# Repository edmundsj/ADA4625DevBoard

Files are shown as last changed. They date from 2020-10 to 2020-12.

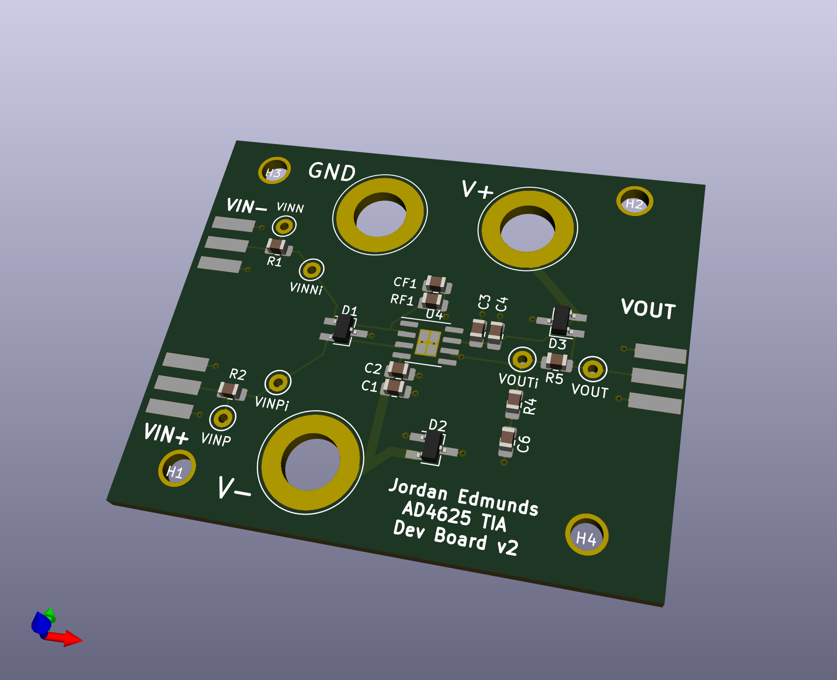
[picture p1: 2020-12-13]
tia_dev_board_image.png

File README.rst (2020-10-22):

ADA4625 TIA Development Board
===============================
This is a development board for the ADA4625 used as a low-noise a transimpedance amplifier.

Features
----------
- Low noise (140nV/rtHz measured at output with 1MOhm resistor, 140fA/rtHz input-referred)
- M3 standoffs
- Separate SMA inputs for + and -
- Power supplied by banana jacks (V+, V-, GND)
- Optional ESD protection diodes and output load filter
- Test points galore

Issues in Version 1
--------------------
- [FIXED v2.1] Gerbers not updated from v1
- [FIXED v2] No labeling of power, input/outputs
- [FIXED v2] board was unnecessarily large
- [FIXED v2]No name / version number on board

Bill of Materials
-------------------

.. csv-table::
    :header-rows: 1
    :file: bom.csv
    :widths: 25 25 25 25 25

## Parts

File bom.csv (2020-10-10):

Part Name | Quantity | Source | Catalog Number | Link
15V TVS Diode | 4 | Digikey | 1727-3813-1-ND | `1727-3813-1-ND <https://www.digikey.com/product-detail/en/nexperia-usa-inc/PESD15VL2BT-215/1727-3813-1-ND/1530818>`_
Banana Jack | 3 | Digikey | 36-575-4-ND | `36-575-4-ND <https://www.digikey.com/products/en?keywords=36-575-4-ND>`_
SMA 50Ohm Terminator | 1 | Digikey | ACX1251-ND | `ACX1251-ND <https://www.digikey.com/products/en?keywords=ACX1251-ND>`_
1MOhm Resistor | 1 | Digikey | 311-1.00MCRCT-ND | `311-1.00MCRCT-ND <https://www.digikey.com/products/en?keywords=311-1.00MCRCT-ND>`_
4.7MOhm Resistor | 1 | Digikey | RHM4.70MAHCT-ND | `RHM4.70MAHCT-ND <https://www.digikey.com/product-detail/en/rohm-semiconductor/KTR10EZPF4704/RHM4-70MAHCT-ND/1983987>`_
0Ohm Resistor | 1 | Digikey | RMCF0805ZT0R00CT-ND | `RMCF0805ZT0R00CT-ND <https://www.digikey.com/product-detail/en/stackpole-electronics-inc/RMCF0805ZT0R00/RMCF0805ZT0R00CT-ND/1942606>`_
ADA4625 opamp | 1 | Digikey | ADA4625-1ARDZ-R7CT-ND | `ADA4625-1ARDZ-R7CT-ND <https://www.digikey.com/product-detail/en/analog-devices-inc/ADA4625-1ARDZ-R7/ADA4625-1ARDZ-R7CT-ND/9385719>`_
10uF decoupling cap | 2 | Digikey | 490-10515-1-ND | `490-10515-1-ND <https://www.digikey.com/products/en?keywords=490-10515-1-ND>`_
100nF decoupling cap | 2 | Digikey | 399-1169-1-ND | `399-1169-1-ND <https://www.digikey.com/product-detail/en/kemet/C0805C104M5RACTU/399-1169-1-ND/411444>`_
1pF feedback cap | 1 | Digikey | 311-4124-1-ND | `311-4124-1-ND <https://www.digikey.com/product-detail/en/yageo/CC0805BRNPO9BN1R0/311-4124-1-ND/8025213>`_
SMA Jack | 3 | Digikey | CON-SMA-EDGE-S-ND | `CON-SMA-EDGE-S-ND <https://www.digikey.com/products/en?keywords=CON-SMA-EDGE-S-ND%09>`_

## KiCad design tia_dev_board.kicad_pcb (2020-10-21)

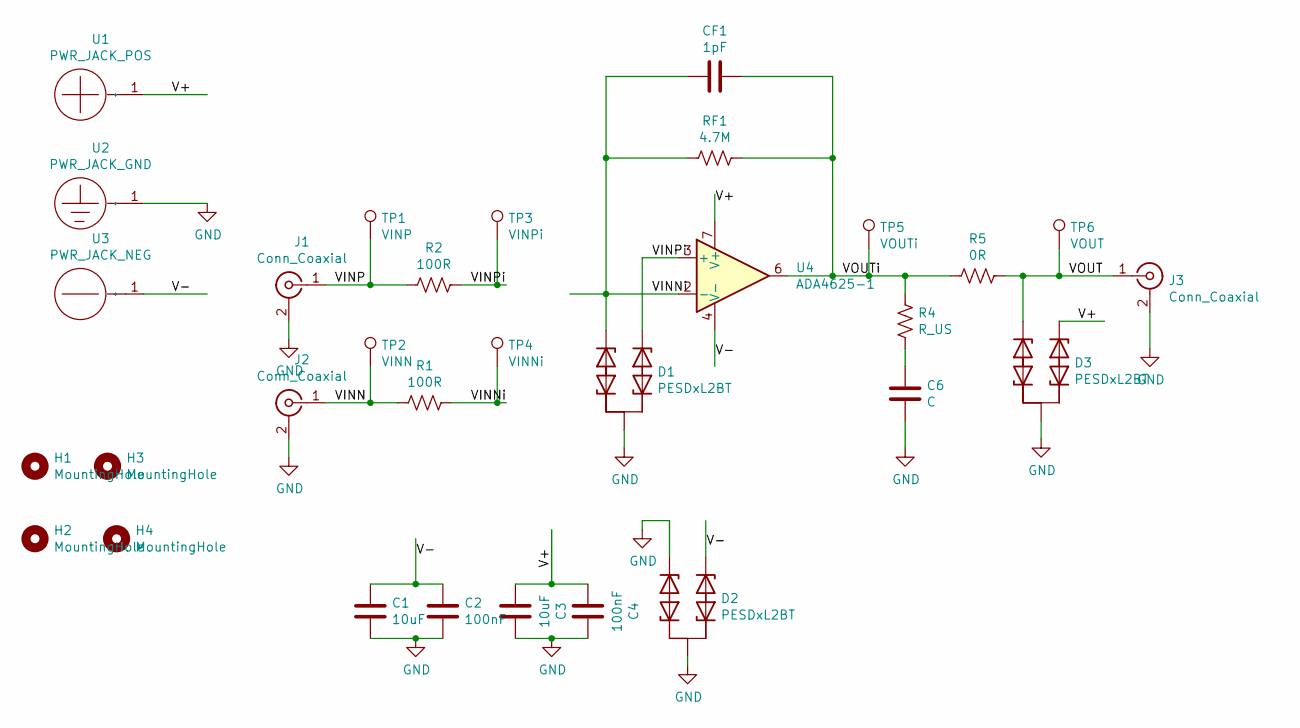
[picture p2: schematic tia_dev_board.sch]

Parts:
C1, C3: 10uF; C_0805_2012Metric_Pad1.15x1.40mm_HandSolder
C2, C4: 100nF; C_0805_2012Metric_Pad1.15x1.40mm_HandSolder
C6: C; C_0805_2012Metric_Pad1.15x1.40mm_HandSolder
CF1: 1pF; C_0805_2012Metric_Pad1.15x1.40mm_HandSolder
D1, D2, D3: PESDxL2BT; SC-59_Handsoldering
H1, H2, H3, H4: MountingHole; m3_mounting_hole
J1, J2, J3: Conn_Coaxial; CON-SMA-EDGE-S
R1, R2: 100R; C_0805_2012Metric_Pad1.15x1.40mm_HandSolder
R4: R_US; C_0805_2012Metric_Pad1.15x1.40mm_HandSolder
R5: 0R; C_0805_2012Metric_Pad1.15x1.40mm_HandSolder
RF1: 4.7M; C_0805_2012Metric_Pad1.15x1.40mm_HandSolder
TP1: VINP; TestPoint_Keystone_5000-5004_Miniature
TP2: VINN; TestPoint_Keystone_5000-5004_Miniature
TP3: VINPi; TestPoint_Keystone_5000-5004_Miniature
TP4: VINNi; TestPoint_Keystone_5000-5004_Miniature
TP5: VOUTi; TestPoint_Keystone_5000-5004_Miniature
TP6: VOUT; TestPoint_Keystone_5000-5004_Miniature
U1: PWR_JACK_POS; Banana_Jack_1Pin
U2: PWR_JACK_GND; Banana_Jack_1Pin
U3: PWR_JACK_NEG; Banana_Jack_1Pin
U4: ADA4625-1; SOIC-8-1EP_3.9x4.9mm_P1.27mm_EP2.29x3mm_ThermalVias

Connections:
/V+: C3.2, C4.2, D3.2 (V2), U1.1, U4.7 (V+)
/V-: C1.1, C2.1, D2.2 (V2), U3.1, U4.4 (V-)
/VINN: J2.1 (In), R1.2, TP2.1
/VINNi: CF1.2, D1.1 (V1), R1.1, RF1.2, TP4.1, U4.2 (-)
/VINP: J1.1 (In), R2.2, TP1.1
/VINPi: D1.2 (V2), R2.1, TP3.1, U4.3 (+)
/VOUT: D3.1 (V1), J3.1 (In), R5.1, TP6.1
/VOUTi: CF1.1, R4.1, R5.2, RF1.1, TP5.1, U4.6
GND: C1.2, C2.2, C3.1, C4.1, C6.2, D1.3 (GND), D2.1 (V1), D2.3 (GND), D3.3 (GND), J1.2 (Ext), J2.2 (Ext), J3.2 (Ext), U2.1
unnamed: C6.1, R4.2

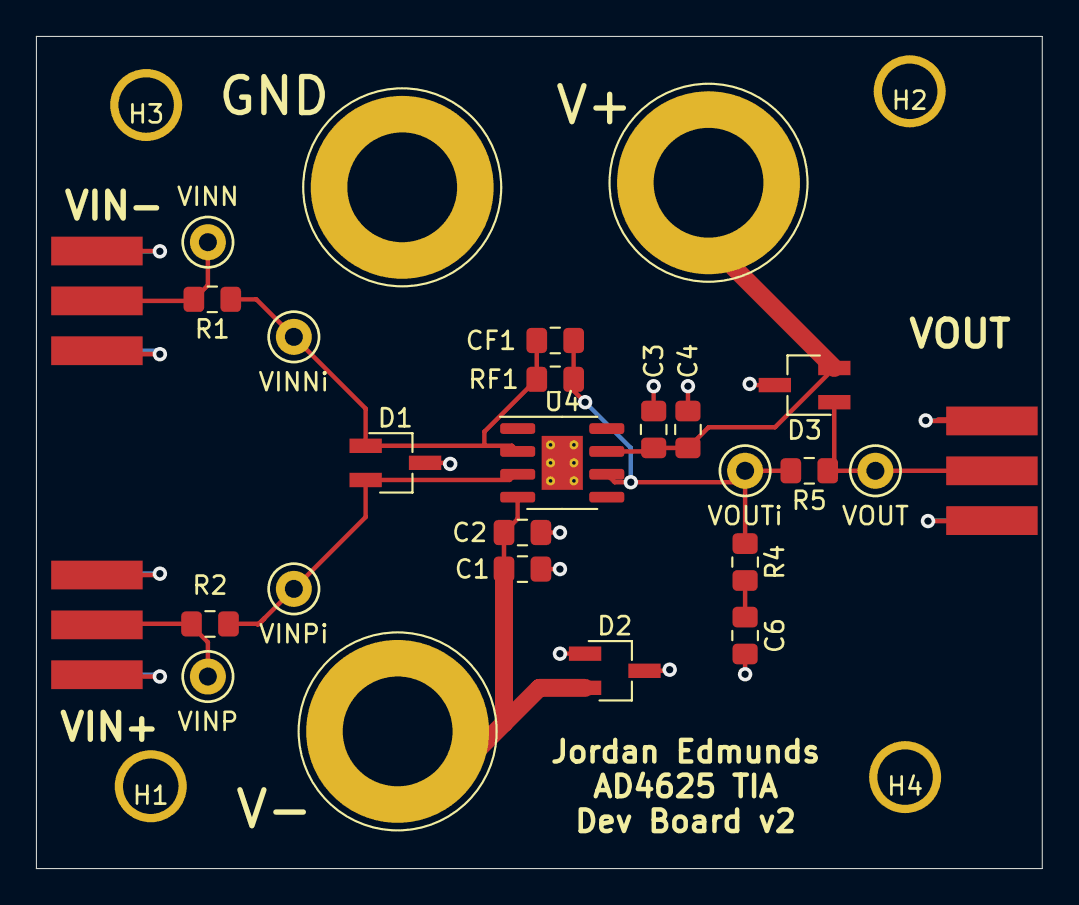
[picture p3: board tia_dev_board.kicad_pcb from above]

Board: 2 copper layers, 55.9 x 46.2 mm, 31 parts (0 on the bottom side), 10 nets.

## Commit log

2020-10-10 first version of TIA dev board created
    [bom.csv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]
2020-10-21 revised PCB according to issues found in version 1
    [tia_dev_board.kicad_pcb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]
2020-10-22 updated gerbers to correct versions, added README
    [tia_dev_board-B_Cu.gbr, tia_dev_board-B_Mask.gbr, tia_dev_board-B_Paste.gbr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]
2020-12-13 added dev board picture
